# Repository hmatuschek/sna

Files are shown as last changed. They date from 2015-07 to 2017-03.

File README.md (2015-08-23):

# Scalar Network Analyzer

A [scalar network analyzer](https://en.wikipedia.org/wiki/Network_analyzer_%28electrical%29) (SNA) measures the amplitude of an output signal of a circuit as a function of the input frequency.

This project provides the circuit, firmware and software to implement a very simple and cheap SNA. It uses a [AD9850 DDS module](http://www.minikits.com.au/electronic-kits/dds-synthesizer/basic-dds/AD9850-DDS-01) as the programmable signal generator and a AD8307 logarithmic amplifier in conjecture with the ADC of an ATMEGA 168 (or the pin compatible ATMEGA 8/48/88/328) to record the input amplitude. The SNA hardware is interfaced via the common RS-232 using a MAX232 level converter. The firmware for the ATMEGA 168 can be found in the firmware directory.

(http://i57.tinypic.com/15fobcp.png)

The client software then provides a simple means of performing the measurements and displays the results. It provides two operating modes. The <emph>poll</emph> mode outputs a fixed frequency and measures the input amplitude while the <emph>scan</emph> mode records the input amplitude as a function of the output frequency. The result is then plotted (see above). 

## Hardware
As mentioned above, the [circuit](https://github.com/hmatuschek/sna/raw/master/doc/compact_scm.pdf) consists of an AD9850 DDS module (visible below) an ATMEGA 168 (partially covered in the picture) to program the DDS and to measure the output voltage of the logarithmic amplifier (AD8307, visible in the top-left corner). The logarithmic amplifier converts the input power over a 51 Ohms resistor into a voltage (0-2.5V) which is a linear function of the input power in dBm. 

the prototype (http://i60.tinypic.com/16k17go.jpg)

The AD8307 can handle up to 17dBm (50mW). The output power of the DDS, however, is only about 0.1mW (-10dBm). To enhence the dynamic range of the SNA, a buffer amplifier (two 2N3904, circuit stolen from  [here](http://rheslip.blogspot.de/2015/08/the-simple-scalar-network-analyser.html), visible at the bottom-right corner) is used to increase the output to about 1-3mW (0-5dBm).  

The SNA is interfaced through the UART (RS-232) of the ATMEGA using a MAX232 level converter (visible in the bottom-left corner). In fact, the hardware is ARDUINO UNO compatible. By flashing the ARDUINO bootloader onto the ATMEGA, the SNA can be programmed easily via the RS-232 interface. 

The [board](https://github.com/hmatuschek/sna/raw/master/doc/compact_brd.pdf) is routed such that it is possible to assemble the circuit on a perfboard without bridges. The board dimensions are kept small. The complete circuit fits into a relatively small TEKO 2/A chassis (57 x 72 x 28 mm). For a better performance, the distance between the AD8307 logarithmic amplifier and the rest of the circuit should be increased and the AD8307 should also be shielded. Due to the lack of shielding, my prototype has a relatively large noise level of about -40dBm.

## Firmware
The firmware for the ATMEGA 168 is extremely simply. It just waits for commands received via the serial interface and either sets the frequency of the DDS module, measures the input amplitude or shuts the DDS chip down. 

### Protocol
The communication protocol is a simple binary protocol. The host (computer) sends a command to the device (SNA) and receives a response. The device never sends data without a request. 

#### Read amplitude
This command will tell the SNA to read the current amplitude.

##### Request 
```
  +------+
  | 0x01 |
  +------+
```
##### Response 
On success 
```
  +------+------+------+
  | 0x00 |  16b value  |
  +------+------+------+
```
The 16bit value (big endian) represents the 16bit fraction of the output voltage of the AD8307. This value maps linear to the dBm value where 0 represents -84dBm and 65535 17dBm.

On error  
```
  +------+
  | 0x01 |
  +------+
```

#### Set frequency
Sets the frequency of the DDS chip.

##### Request 
```
  +------+------+------+------+------+
  | 0x02 |     32b frequency word    |
  +------+------+------+------+------+
```
The 32 bit frequency word (big endian) represents the fraction of the output frequency relative to the oscillator frequency (125MHz). I.e. F_out = 125MHz * FW/2^32

##### Response 
On success 
```
  +------+
  | 0x00 |
  +------+
```
On error  
```
  +------+
  | 0x01 |
  +------+
```

#### Set frequency & read amplitude
Sets the frequency of the DDS chip and reads the current amplitude value.

##### Request 
(see set frequency command above)
```
  +------+------+------+------+------+
  | 0x03 |     32b frequency word    |
  +------+------+------+------+------+
```

##### Response 
On success 
```
  +------+------+------+
  | 0x00 |  16b value  |
  +------+------+------+
```
(see read amplitude command above)

On error  
```
  +------+
  | 0x01 |
  +------+
```

#### Shutdown DDS

This command will disable the DDS output. 

##### Request 
```
  +------+
  | 0x04 |
  +------+
```

##### Response 
On success 
```
  +------+
  | 0x00 |
  +------+
```

On error  
```
  +------+
  | 0x01 |
  +------+
```

## License
SNA - A simple scalar network analyzer. (c) 2015 Hannes Matuschek <hmatuschek at gmail dot com>

The hardware is licensed under [Createtive Commons BY-SA 4.0](https://creativecommons.org/licenses/by-sa/4.0/) and the software under [GPL 2.0+](https://www.gnu.org/licenses/old-licenses/gpl-2.0.txt) (see below).

This program is free software; you can redistribute it and/or
modify it under the terms of the GNU General Public License
as published by the Free Software Foundation; either version 2
of the License, or (at your option) any later version.</p>

This program is distributed in the hope that it will be useful,
but WITHOUT ANY WARRANTY; without even the implied warranty of
MERCHANTABILITY or FITNESS FOR A PARTICULAR PURPOSE.  See the
GNU General Public License for more details.

You should have received a copy of the GNU General Public License
along with this program; if not, write to the Free Software
Foundation, Inc., 51 Franklin Street, Fifth Floor, Boston, MA  02110-1301, USA.

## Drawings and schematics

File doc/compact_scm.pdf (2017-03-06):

## R9R¹⁰

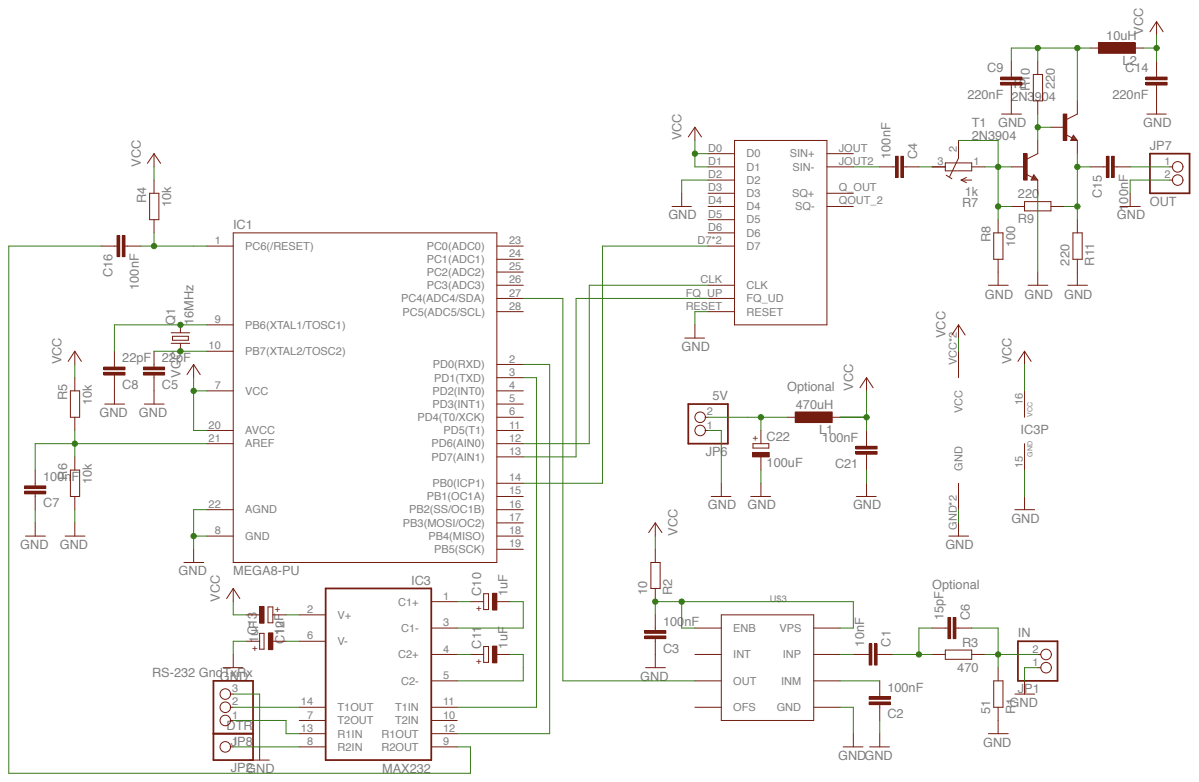
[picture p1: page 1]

RESET

VCC VCC*2 GND GND*2

PB7(XTAL2/TOSC2) 10

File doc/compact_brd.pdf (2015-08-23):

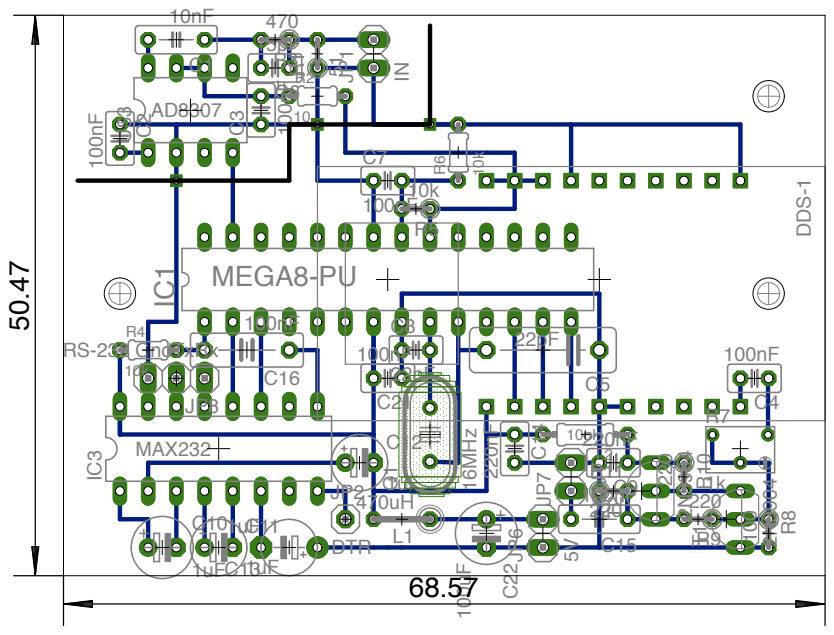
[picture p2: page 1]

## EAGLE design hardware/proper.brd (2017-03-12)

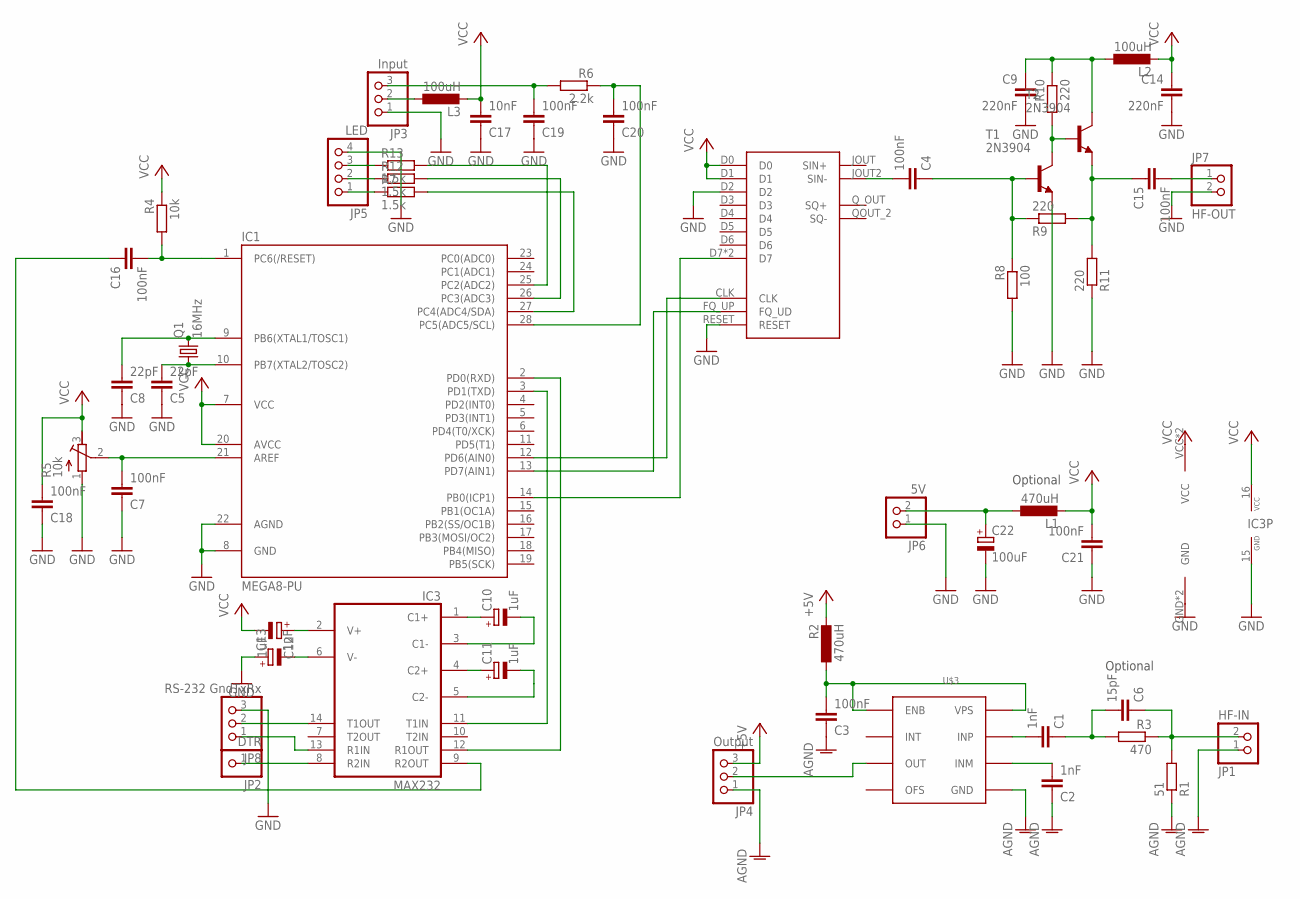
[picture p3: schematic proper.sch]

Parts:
C1, C2: 1nF; C025-025X050
C3, C4, C7, C19, C20, C21: 100nF; C025-025X050
C5: 22pF; C102-043X133
C6: 15pF; C050-025X075
C8: 22pF; C025-025X050
C9: 220nF; C025-025X050
C10, C11, C12, C13: 1uF; E2,5-5
C14: 220nF; C050-025X075
C15, C18: 100nF; C050-025X075
C16: 100nF; C075-032X103
C17: 10nF; C025-025X050
C22: 100uF; E2,5-6
IC1: MEGA8-PU; DIL28-3
IC3: MAX232; DIL16
JP1: HF-IN; 1X02
JP2: DTR; 1X01
JP3: Input; 1X03
JP4: Output; 1X03
JP5: LED; 1X04
JP6: 5V; 1X02
JP7: HF-OUT; 1X02
JP8: RS-232 GndTxRx; 1X03
L1: 470uH; 0207/5V
L2: 100uH; 0207/12
L3: 100uH; 0207/2V
Q1: 16MHz; HC49U-V
R1: 51; 0204V
R2: 470uH; 0204/5
R3: 470; 0204/5
R4: 10k; 0204/5
R5: 10k; RTRIM64W
R6: 2.2k; 0204V
R7, R12, R13: 1.5k; 0204/5
R8: 100; 0204V
R9, R10, R11: 220; 0204V
T1, T2: 2N3904; TO92-EBC
U$1: DDS-1
U$3: AD8307; DIL08

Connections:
+5V: JP4.3, R2.2
GND: C5.1, C7.1, C8.1, C9.2, C13.+, C14.2, C17.1, C18.1, C19.1, C20.1, C21.1, C22.-, IC1.8 (GND), IC1.22 (AGND), IC3.15 (GND), JP3.1, JP5.4, JP6.1, JP7.2, JP8.3, R5.1 (A), R8.2, R11.1, T1.E, U$1.D2, U$1.GND, U$1.GND2 (GND), U$1.RESET
unnamed: C4.2, U$1.JOUT2 (SIN-)
unnamed: C6.1, JP1.2, R1.2, R3.1
unnamed: C1.2, U$3.8 (INP)
unnamed: C2.2, U$3.1 (INM)
unnamed: C5.2, IC1.10 (PB7(XTAL2/TOSC2)), Q1.1
unnamed: C8.2, IC1.9 (PB6(XTAL1/TOSC1)), Q1.2
unnamed: C12.+, IC3.2 (V+)
unnamed: C3.2, R2.1, U$3.6 (ENB), U$3.7 (VPS)
unnamed: JP4.2, U$3.4 (OUT)
unnamed: C22.+, JP6.2, L1.1
unnamed: IC3.14 (T1OUT), JP8.2
unnamed: C1.1, C6.2, R3.2
unnamed: C4.1, R8.1, R9.1, T1.B
unnamed: C20.2, IC1.28 (PC5(ADC5/SCL)), R6.1
unnamed: IC1.13 (PD7(AIN1)), U$1.FQ_UP (FQ_UD)
unnamed: C13.-, IC3.6 (V-)
unnamed: IC1.3 (PD1(TXD)), IC3.11 (T1IN)
unnamed: IC1.12 (PD6(AIN0)), U$1.CLK
unnamed: IC1.14 (PB0(ICP1)), U$1.D7, U$1.D7_2 (D7)
unnamed: C9.1, L2.1, R10.1, T2.C
unnamed: R10.2, T1.C, T2.B
unnamed: IC1.2 (PD0(RXD)), IC3.12 (R1OUT)
unnamed: C15.2, JP7.1
unnamed: C15.1, R9.2, R11.2, T2.E
unnamed: C16.2, IC1.1 (PC6(/RESET)), R4.2
unnamed: C16.1, IC3.9 (R2OUT)
unnamed: IC3.8 (R2IN), JP2.1
unnamed: C7.2, IC1.21 (AREF), R5.2 (S)
unnamed: JP3.2, L3.1
unnamed: JP5.1, R7.1
unnamed: JP5.2, R12.1
unnamed: JP5.3, R13.1
unnamed: C2.1, C3.1, JP1.1, JP4.1, R1.1, U$3.2 (GND)
unnamed: IC3.13 (R1IN), JP8.1
unnamed: IC1.27 (PC4(ADC4/SDA)), R7.2
unnamed: IC1.26 (PC3(ADC3)), R12.2
unnamed: IC1.25 (PC2(ADC2)), R13.2
unnamed: C10.+, IC3.1 (C1+)
unnamed: C10.-, IC3.3 (C1-)
unnamed: C11.+, IC3.4 (C2+)
unnamed: C11.-, IC3.5 (C2-)
unnamed: C19.2, JP3.3, R6.2
VCC: C12.-, C14.1, C17.2, C18.2, C21.2, IC1.7 (VCC), IC1.20 (AVCC), IC3.16 (VCC), L1.2, L2.2, L3.2, R4.1, R5.3 (E), U$1.D0, U$1.D1, U$1.VCC, U$1.VCC2 (VCC)

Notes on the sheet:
Optional

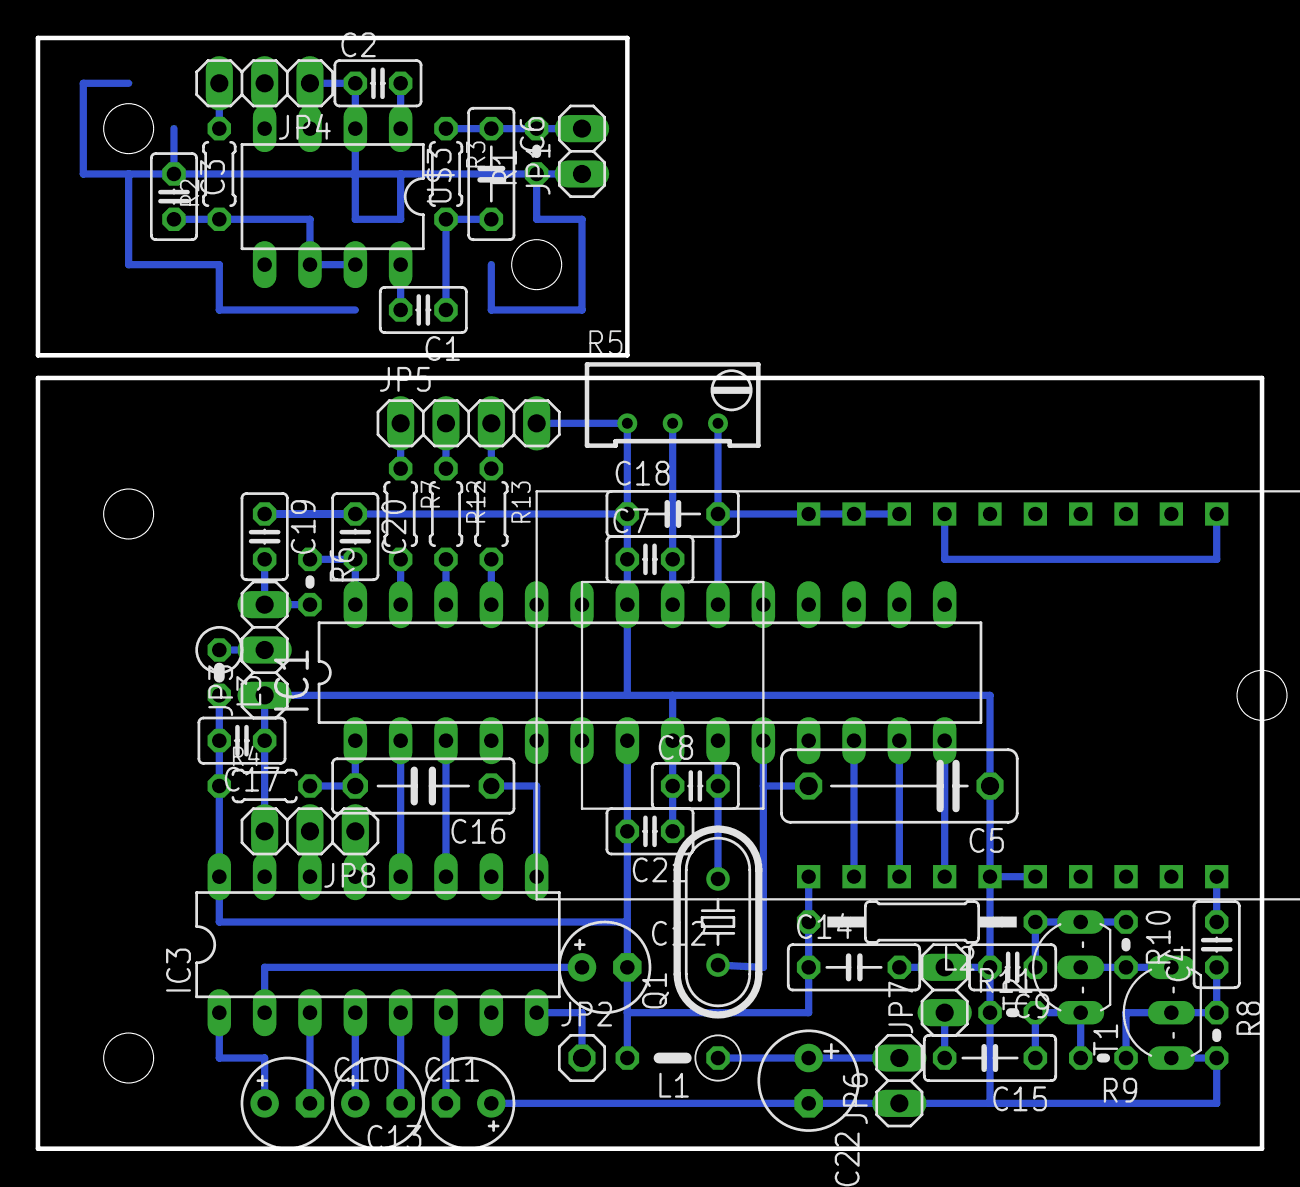
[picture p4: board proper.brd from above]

Board: 2 copper layers, 68.6 x 62.2 mm, 53 parts (0 on the bottom side), 45 nets.

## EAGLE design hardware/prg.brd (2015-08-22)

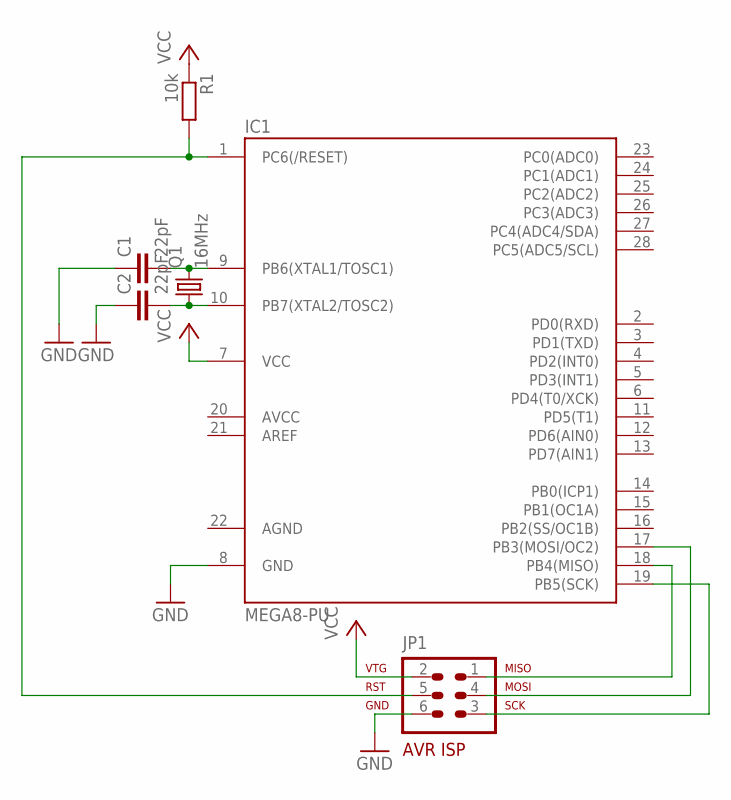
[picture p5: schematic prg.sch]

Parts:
C1: 22pF; C025-025X050
C2: 22pF; C050-025X075
IC1: MEGA8-PU; DIL28-3
JP1: AVR-ISP-6
Q1: 16MHz; HC49/S
R1: 10k; 0204/7

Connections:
AGND: IC1.22 (AGND)
GND: C1.1, C2.1, IC1.8 (GND), JP1.6
unnamed: IC1.19 (PB5(SCK)), JP1.3
unnamed: IC1.17 (PB3(MOSI/OC2)), JP1.4
unnamed: IC1.18 (PB4(MISO)), JP1.1
unnamed: C2.2, IC1.10 (PB7(XTAL2/TOSC2)), Q1.1
unnamed: C1.2, IC1.9 (PB6(XTAL1/TOSC1)), Q1.2
unnamed: IC1.1 (PC6(/RESET)), JP1.5, R1.2
VCC: IC1.7 (VCC), JP1.2, R1.1

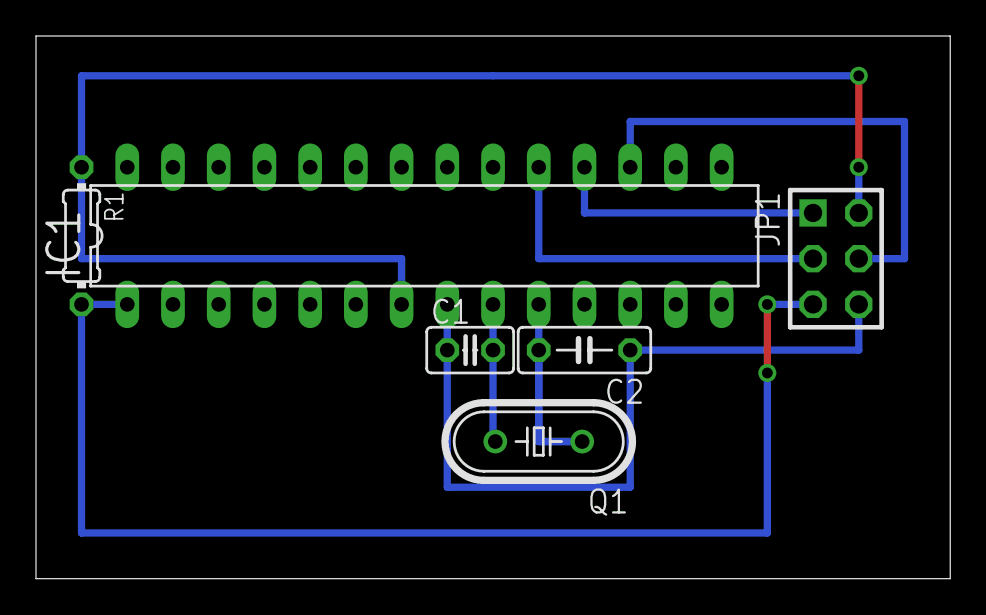
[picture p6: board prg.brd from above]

Board: 2 copper layers, 50.8 x 30.1 mm, 6 parts (0 on the bottom side), 8 nets.

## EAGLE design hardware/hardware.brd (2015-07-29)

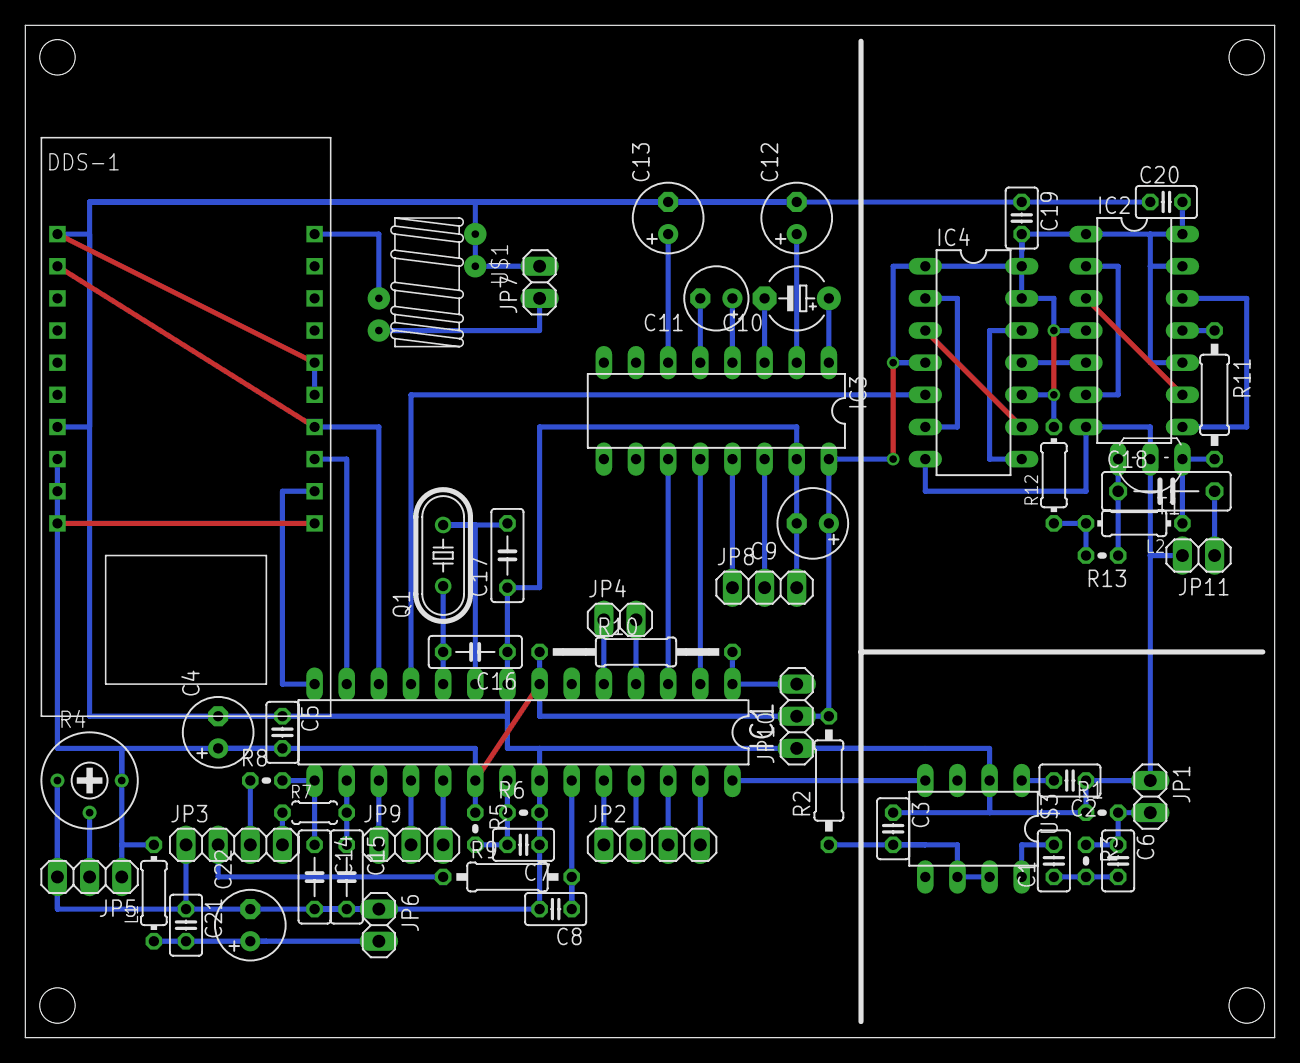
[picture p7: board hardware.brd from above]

Board: 2 copper layers, 98.7 x 80.0 mm, 57 parts (0 on the bottom side), 57 nets.

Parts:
C1: 10nF; C025-025X050
C2, C3, C5, C7, C8, C19, C20, C21: 100nF; C025-025X050
C4, C22: 100uF; E2,5-6
C6: 15pF; C025-025X050
C9, C12, C13: 1uF; E2,5-6
C10: 1uF; E5-5
C11: 1uF; E2,5-5
C14, C15: 100nF; C050-025X075
C16, C17: 22pF; C050-025X075
C18: 100nF; C075-032X103
IC1: ATMEGA168-20P; DIL28-3
IC2, IC4: 74AC74N; DIL14
IC3: MAX232; DIL16
JP1: IN; 1X02
JP2: DISP DATA; 1X04
JP3: ROT; 1X04
JP4: DISP CTRL; 1X02
JP5: DISP SUPPLY; 1X03
JP6: 5V; 1X02
JP7: OUT; 1X02
JP8: RS-232; 1X03
JP9: PRG1; 1X03
JP10: PRG2; 1X03
JP11: F-IN; 1X02
L1, L2: 470uH; 0204/7
Q1: 16MHz; HC49/S
R1: 51; 0204V
R2: 10; 0207/10
R3: 470; 0204V
R4: 10k; RTRIM3339P
R5, R6, R8, R13: 10k; 0204V
R7: 10k; 0204/5
R9: 10k; 0207/10
R10: 10k; 0207/15
R11: 470; 0207/10
R12: 470; 0204/7
T1: BF199; TO92-CEB
U$1: T37_TRANSFORMER
U$2: DDS-1
U$3: AD8307; DIL08

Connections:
GND: C2.1, C3.1, C4.-, C5.1, C7.1, C8.2, C9.-, C12.-, C13.-, C14.2, C15.2, C16.1, C17.1, C19.1, C20.1, C21.1, C22.-, IC1.8, IC1.22, IC2.7, IC3.15, IC4.7, JP1.1, JP3.1, JP5.3, JP6.1, JP7.2, JP8.3, JP10.1, JP11.2, R1.1, R4.1, R6.2, T1.E, U$1.C1A, U$1.C2A, U$2.D2, U$2.GND, U$2.GND2, U$2.RESET, U$3.2
unnamed: IC1.17, JP9.1
unnamed: C6.1, JP1.2, R1.2, R3.1
unnamed: C1.2, U$3.8
unnamed: C2.2, U$3.1
unnamed: IC1.18, JP9.2
unnamed: IC1.19, JP9.3
unnamed: IC1.1, JP10.3, R10.2
unnamed: C3.2, R2.1, U$3.6, U$3.7
unnamed: IC1.28, U$3.4
unnamed: C21.2, C22.+, JP6.2, L1.1
unnamed: IC3.14, JP8.2
unnamed: C1.1, C6.2, R3.2
unnamed: U$1.C1B, U$2.JOUT2
unnamed: JP7.1, U$1.C2B
unnamed: IC1.13, U$2.FQ_UP
unnamed: IC1.27, JP2.4
unnamed: IC1.3, IC3.11
unnamed: IC1.26, JP2.3
unnamed: IC1.25, JP2.2
unnamed: IC1.24, JP2.1
unnamed: C15.1, IC1.16, R7.2
unnamed: IC1.2, IC3.12
unnamed: C14.1, IC1.15, R8.2
unnamed: JP3.4, R7.1
unnamed: IC1.4, JP4.2
unnamed: IC1.14, U$2.CLK
unnamed: IC1.5, JP4.1
unnamed: JP5.2, R4.2
unnamed: C7.2, IC1.21, R5.2, R6.1
unnamed: IC1.12, U$2.D7, U$2.D7_2
unnamed: JP3.3, R8.1
unnamed: JP3.2, R9.1
unnamed: C8.1, IC1.23, R9.2
unnamed: IC3.13, JP8.1
unnamed: C12.+, IC3.2
unnamed: C13.+, IC3.6
unnamed: C16.2, IC1.10, Q1.1
unnamed: C10.+, IC3.1
unnamed: C10.-, IC3.3
unnamed: C11.+, IC3.4
unnamed: C11.-, IC3.5
unnamed: C17.2, IC1.9, Q1.2
unnamed: IC4.2, IC4.6
unnamed: IC1.11, IC4.5
unnamed: IC2.8, IC2.12
unnamed: IC2.2, IC2.6
unnamed: IC4.8, IC4.12
unnamed: IC2.3, IC2.9
unnamed: IC2.5, IC4.11
unnamed: IC4.3, IC4.9
unnamed: IC2.11, R11.1
unnamed: L2.1, R11.2, T1.C
unnamed: L2.2, R12.1, R13.2
unnamed: C18.1, R13.1, T1.B
unnamed: C18.2, JP11.1
VCC: C4.+, C5.2, C9.+, C19.2, C20.2, IC1.7, IC1.20, IC2.1, IC2.4, IC2.10, IC2.13, IC2.14, IC3.16, IC4.1, IC4.4, IC4.10, IC4.13, IC4.14, JP5.1, JP10.2, L1.2, R2.2, R4.3, R5.1, R10.1, R12.2, U$2.D0, U$2.D1, U$2.VCC, U$2.VCC2

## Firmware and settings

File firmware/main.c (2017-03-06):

#include "uart.h"
#include "ad9850.h"
#include "adc.h"

#include <inttypes.h>
#include <avr/io.h>
#include <util/delay.h>
#include <avr/interrupt.h>


int main(void) {
  // Allow hardware to power-up
  _delay_ms(100);
  // Init UART
  uart_init(UART_BAUD_9600);
  // Init adc
  adc_init();
  // Init oscillator
  ad9850_init();

  // config LED pins (POWER, TX, RX)
  DDRC |= ((1<<DDC4) || (1<<DDC3) || (1<<DDC2));
  PORTC &= ~((1<<PORTC4) || (1<<PORTC3) || (1<<PORTC2));

  sei();

  // Signal power up
  PORTC |= (1<<PORTC4);

  while (1) {
    // Wait for command
    uint8_t cmd = uart_getc();

    // Dispatch by cmd byte
    switch( cmd ) {
    // GET_VALUE
    case 0x01: {
      PORTC |= (1<<PORTC2);
      uint16_t v = 0;
      // Short delay before starting measurement
      _delay_ms(10);
      for (uint8_t i=0; i<64; i++) { v += adc_get(); }
      uart_putc(0x00); uart_putc(v>>8); uart_putc(v&0xff);
      PORTC &= ~(1<<PORTC3);
    }
      break;

    // SET_FREQUENCY
    case 0x02: {
      PORTC |= (1<<PORTC3);
      // Receive 32 bit uint
      uint32_t factor = uart_getc();
      factor = ( (factor<<8) | uart_getc() );
      factor = ( (factor<<8) | uart_getc() );
      factor = ( (factor<<8) | uart_getc() );
      // Set factor
      ad9850_set(factor);
      // ok.
      uart_putc(0x00);
    }
      break;

    // SET & GET
    case 0x03: {
      PORTC |= ((1<<PORTC3) || (1<<PORTC2));
      // Receive 32 bit uint
      uint32_t factor = uart_getc();
      factor = ( (factor<<8) | uart_getc() );
      factor = ( (factor<<8) | uart_getc() );
      factor = ( (factor<<8) | uart_getc() );
      // set factor
      ad9850_set(factor);
      // Short delay before starting measurement
      _delay_ms(10);
      // Measure
      uint16_t v = 0;
      // adc_get() returns a 10bit uint.
      // -> summing 64 10bit values will result into a 16bit uint
      for (uint8_t i=0; i<64; i++) { v += adc_get(); }
      // ... done. Send result
      uart_putc(0x00); uart_putc(v>>8); uart_putc(v&0xff);
      PORTC &= ~(1<<PORTC2);
    }
      break;

    // SHUTDOWN
    case 0x04:
      PORTC &= ~(1<<PORTC3);
      ad9850_shutdown();
      uart_putc(0x00);
      break;

    // else ERROR
    default:
      uart_putc(0xff);
      break;
    }
  }

  return 0;
}

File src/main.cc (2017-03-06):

#include <QApplication>

#include "sna.hh"
#include "logger.hh"
#include "mainwindow.hh"
#include "portdialog.hh"
#include <iostream>


int main(int argc, char *argv[]) {
  QApplication app(argc, argv);
  app.setApplicationName("SNA");
  app.setOrganizationName("io.github.hmatuschek");
  app.setOrganizationDomain("hmatuschek.github.io");

  Logger::get().addHandler(new StreamLogHandler(LOG_DEBUG, std::cerr));

  PortDialog dialog;
  if (QDialog::Accepted != dialog.exec()) { return 0; }

  QSettings settings; settings.setValue("ref", dialog.refVoltage());

  QString systemLocation = dialog.systemLocation();
  SNA sna(systemLocation, dialog.refVoltage());

  MainWindow win(sna);
  win.show();

  app.exec();

  return 0;
}

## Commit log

2015-07-31 Updated hardware.
    [compact.brd, compact.sch, hardware.sch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]
2015-08-05 Fixed circuit and board.
    [compact.brd, compact.sch]
2015-08-23 Fixed board and schematic PDFs.
2015-08-23 Fixed firmware to use ADC noise reduction mode.
    [adc.c]
2017-03-06 Fixed minors, added win build.
    [proper.brd, proper.sch]
2017-03-12 Fixed minor.
    [proper.brd]
